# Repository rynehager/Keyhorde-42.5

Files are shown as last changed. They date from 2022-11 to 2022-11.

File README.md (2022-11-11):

# Keyhorde-42.5
Babby's first bad keyboard PCB

This is a not-quite 40%, not-quite 50% keyboard being made for the founding members of Keyhorde with the following layout:
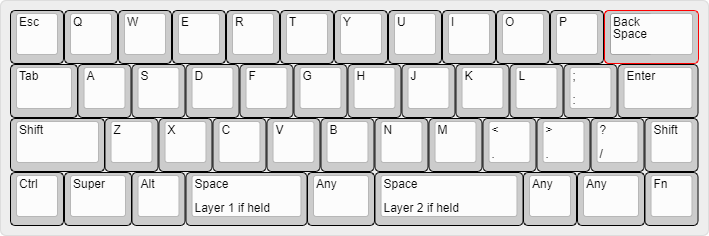
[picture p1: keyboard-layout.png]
An 11-key-wide, four-row-tall compact keyboard somwhere between a standard 40% and 50% layout


The purpose is to design a compact, USB Type-C caseless keyboard with a bare PCB aesthetic and a layout that doesn't interfere with general writing, including commonly used punctuation, but which is also as portable as possible and generally compatible with keyset options — i.e., it does not require custom or incorrect legend keys when using a set with wide compatibility. 

Schematics and layout designed in KiCAD, licensing CC0 so feel free to reuse, remix, make, sell, etc. whatever you dig bby just don't hold me responsible.

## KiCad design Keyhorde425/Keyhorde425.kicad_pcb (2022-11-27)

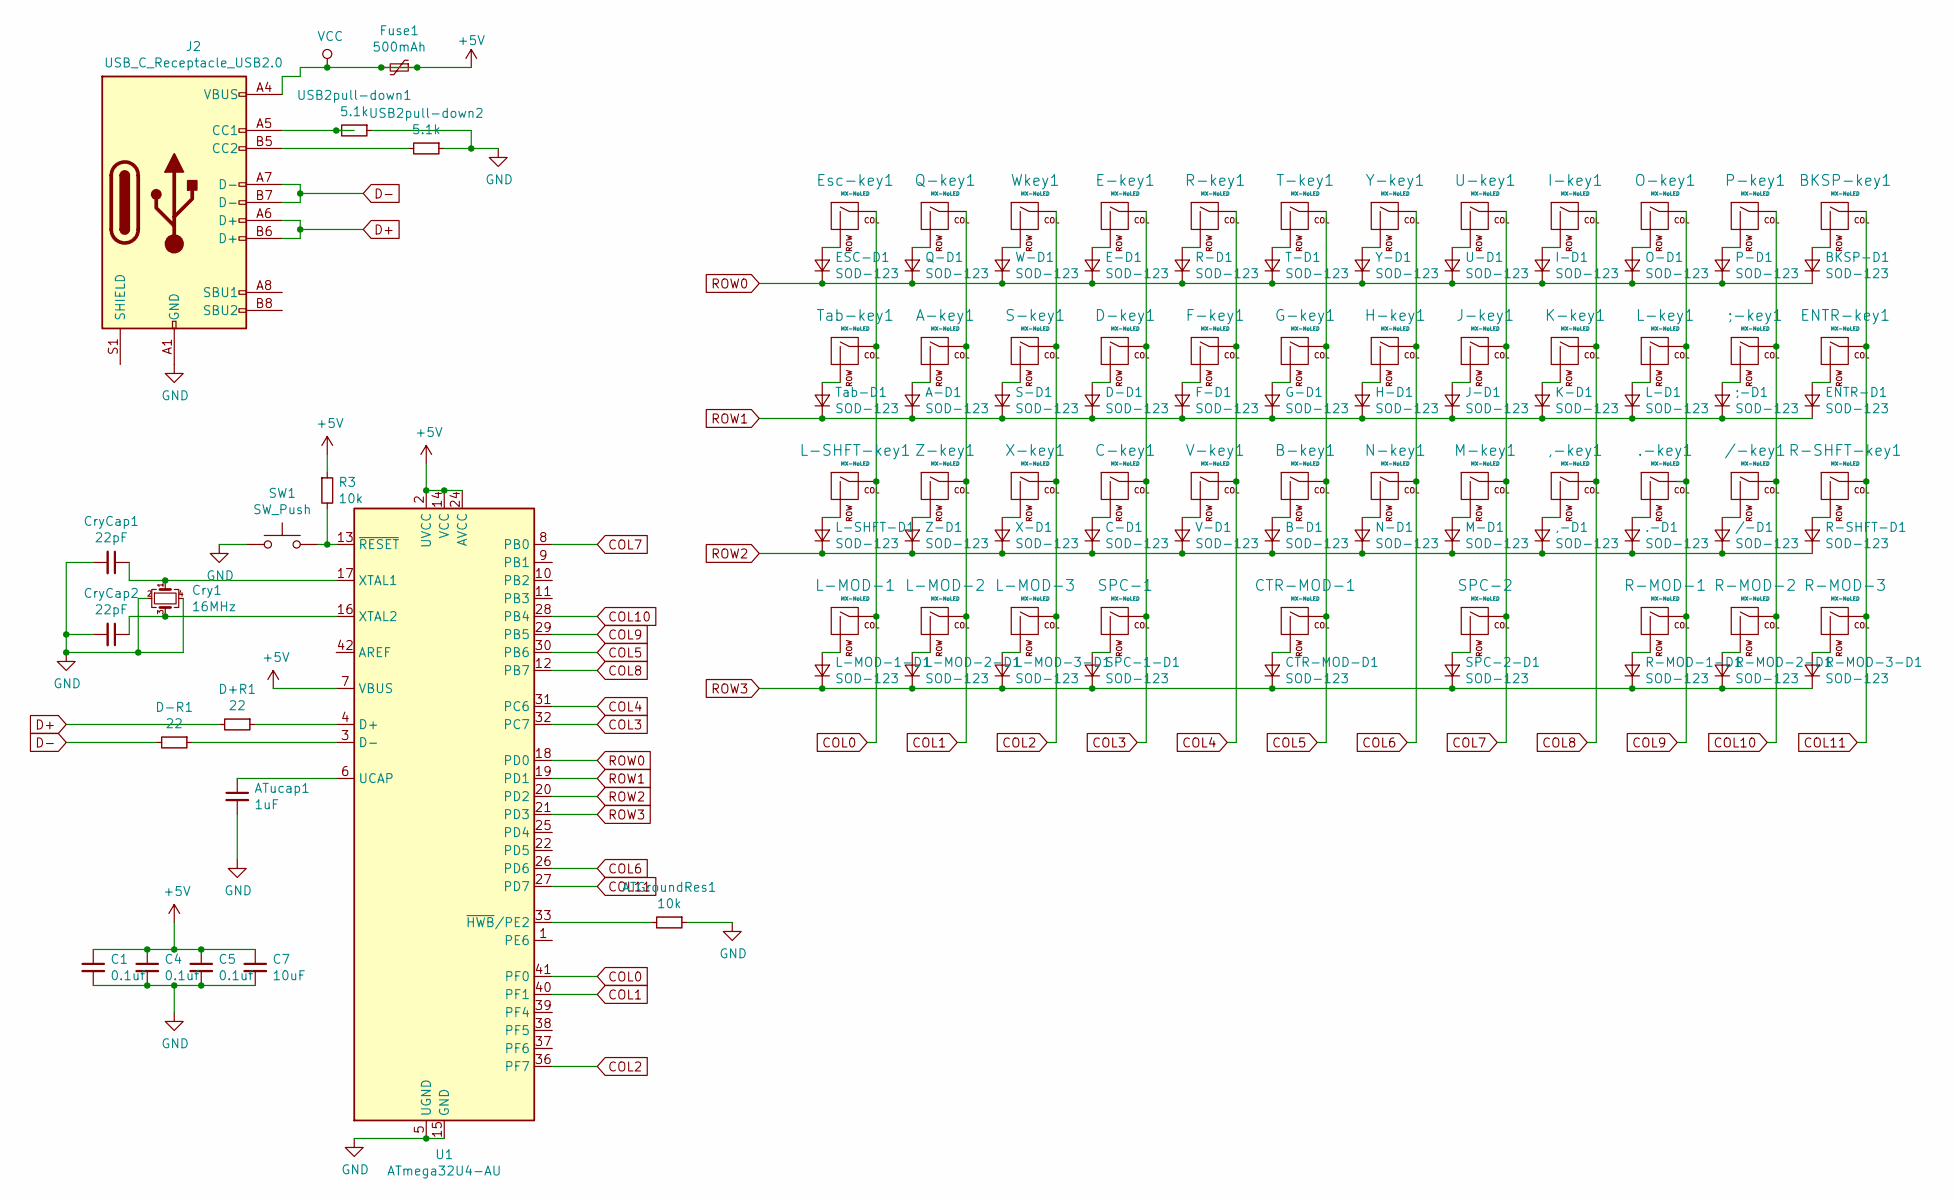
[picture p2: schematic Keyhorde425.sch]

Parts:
,-D1: SOD-123; D_SOD-123
,-key1: MX-NoLED; MX-1U-NoLED
.-D1: SOD-123; D_SOD-123
.-key1: MX-NoLED; MX-1U-NoLED
/-D1: SOD-123; D_SOD-123
/-key1: MX-NoLED; MX-1U-NoLED
;-D1: SOD-123; D_SOD-123
;-key1: MX-NoLED; MX-1U-NoLED
A-D1: SOD-123; D_SOD-123
A-key1: MX-NoLED; MX-1U-NoLED
ATGroundRes1: 10k; R_0805_2012Metric
ATucap1: 1uF; C_0805_2012Metric
B-D1: SOD-123; D_SOD-123
B-key1: MX-NoLED; MX-1U-NoLED
BKSP-D1: SOD-123; D_SOD-123
BKSP-key1: MX-NoLED; MX-1.75U-NoLED
C1, C4, C5: 0.1uf; C_0805_2012Metric
C7: 10uF; C_0805_2012Metric
C-D1: SOD-123; D_SOD-123
C-key1: MX-NoLED; MX-1U-NoLED
CTR-MOD-1: MX-NoLED; MX-1.25U-NoLED
CTR-MOD-D1: SOD-123; D_SOD-123
Cry1: 16MHz; Crystal_SMD_3225-4Pin_3.2x2.5mm
CryCap1, CryCap2: 22pF; C_0805_2012Metric
D+R1: 22; R_0805_2012Metric
D-D1: SOD-123; D_SOD-123
D-R1: 22; R_0805_2012Metric
D-key1: MX-NoLED; MX-1U-NoLED
E-D1: SOD-123; D_SOD-123
E-key1: MX-NoLED; MX-1U-NoLED
ENTR-D1: SOD-123; D_SOD-123
ENTR-key1: MX-NoLED; MX-1.5U-NoLED
ESC-D1: SOD-123; D_SOD-123
Esc-key1: MX-NoLED; MX-1U-NoLED
F-D1: SOD-123; D_SOD-123
F-key1: MX-NoLED; MX-1U-NoLED
Fuse1: 500mAh; Fuse_1206_3216Metric
G-D1: SOD-123; D_SOD-123
G-key1: MX-NoLED; MX-1U-NoLED
H-D1: SOD-123; D_SOD-123
H-key1: MX-NoLED; MX-1U-NoLED
I-D1: SOD-123; D_SOD-123
I-key1: MX-NoLED; MX-1U-NoLED
J2: USB_C_Receptacle_USB2.0; USB_C_Receptacle_Amphenol_12401610E4-2A
J-D1: SOD-123; D_SOD-123
J-key1: MX-NoLED; MX-1U-NoLED
K-D1: SOD-123; D_SOD-123
K-key1: MX-NoLED; MX-1U-NoLED
L-D1: SOD-123; D_SOD-123
L-MOD-1, L-MOD-3: MX-NoLED; MX-1U-NoLED
L-MOD-1-D1, L-MOD-2-D1, L-MOD-3-D1: SOD-123; D_SOD-123
L-MOD-2: MX-NoLED; MX-1.25U-NoLED
L-SHFT-D1: SOD-123; D_SOD-123
L-SHFT-key1: MX-NoLED; MX-1.75U-NoLED
L-key1: MX-NoLED; MX-1U-NoLED
M-D1: SOD-123; D_SOD-123
M-key1: MX-NoLED; MX-1U-NoLED
N-D1: SOD-123; D_SOD-123
N-key1: MX-NoLED; MX-1U-NoLED
O-D1: SOD-123; D_SOD-123
O-key1: MX-NoLED; MX-1U-NoLED
P-D1: SOD-123; D_SOD-123
P-key1: MX-NoLED; MX-1U-NoLED
Q-D1: SOD-123; D_SOD-123
Q-key1: MX-NoLED; MX-1U-NoLED
R3: 10k; R_0805_2012Metric
R-D1: SOD-123; D_SOD-123
R-MOD-1, R-MOD-3: MX-NoLED; MX-1U-NoLED
R-MOD-1-D1, R-MOD-2-D1, R-MOD-3-D1: SOD-123; D_SOD-123
R-MOD-2: MX-NoLED; MX-1.25U-NoLED
R-SHFT-D1: SOD-123; D_SOD-123
R-SHFT-key1: MX-NoLED; MX-1U-NoLED
R-key1: MX-NoLED; MX-1U-NoLED
S-D1: SOD-123; D_SOD-123
S-key1: MX-NoLED; MX-1U-NoLED
SPC-1: MX-NoLED; MX-2.25U-NoLED
SPC-1-D1, SPC-2-D1: SOD-123; D_SOD-123
SPC-2: MX-NoLED; MX-2.75U-NoLED
SW1: SW_Push; Reset_Pretty
T-D1: SOD-123; D_SOD-123
T-key1: MX-NoLED; MX-1U-NoLED
Tab-D1: SOD-123; D_SOD-123
Tab-key1: MX-NoLED; MX-1.25U-NoLED
U1: ATmega32U4-AU; LQFP-44_10x10mm_P0.8mm
U-D1: SOD-123; D_SOD-123
U-key1: MX-NoLED; MX-1U-NoLED
USB2pull-down1, USB2pull-down2: 5.1k; R_0805_2012Metric
V-D1: SOD-123; D_SOD-123
V-key1: MX-NoLED; MX-1U-NoLED
W-D1: SOD-123; D_SOD-123
Wkey1: MX-NoLED; MX-1U-NoLED
X-D1: SOD-123; D_SOD-123
X-key1: MX-NoLED; MX-1U-NoLED
Y-D1: SOD-123; D_SOD-123
Y-key1: MX-NoLED; MX-1U-NoLED
Z-D1: SOD-123; D_SOD-123
Z-key1: MX-NoLED; MX-1U-NoLED

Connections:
+5V: C1.1, C4.1, C5.1, C7.1, Fuse1.1, Fuse1.2, J2.A4 (VBUS), J2.A9 (VBUS), J2.B4 (VBUS), J2.B9 (VBUS), R3.1, U1.2 (UVCC), U1.7 (VBUS), U1.14 (VCC), U1.24 (AVCC), U1.34 (VCC), U1.44 (AVCC)
COL0: Esc-key1.1 (COL), L-MOD-1.1 (COL), L-SHFT-key1.1 (COL), Tab-key1.1 (COL), U1.41 (PF0)
COL1: A-key1.1 (COL), L-MOD-2.1 (COL), Q-key1.1 (COL), U1.40 (PF1), Z-key1.1 (COL)
COL2: L-MOD-3.1 (COL), S-key1.1 (COL), U1.36 (PF7), Wkey1.1 (COL), X-key1.1 (COL)
COL3: C-key1.1 (COL), D-key1.1 (COL), E-key1.1 (COL), SPC-1.1 (COL), U1.32 (PC7)
COL4: F-key1.1 (COL), R-key1.1 (COL), U1.31 (PC6), V-key1.1 (COL)
COL5: B-key1.1 (COL), CTR-MOD-1.1 (COL), G-key1.1 (COL), T-key1.1 (COL), U1.30 (PB6)
COL6: H-key1.1 (COL), N-key1.1 (COL), U1.26 (PD6), Y-key1.1 (COL)
COL7: J-key1.1 (COL), M-key1.1 (COL), SPC-2.1 (COL), U1.8 (PB0), U-key1.1 (COL)
COL8: ,-key1.1 (COL), I-key1.1 (COL), K-key1.1 (COL), U1.12 (PB7)
COL9: .-key1.1 (COL), L-key1.1 (COL), O-key1.1 (COL), R-MOD-1.1 (COL), U1.29 (PB5)
COL10: /-key1.1 (COL), ;-key1.1 (COL), P-key1.1 (COL), R-MOD-2.1 (COL), U1.28 (PB4)
COL11: BKSP-key1.1 (COL), ENTR-key1.1 (COL), R-MOD-3.1 (COL), R-SHFT-key1.1 (COL), U1.27 (PD7)
D+: D+R1.2, J2.A6 (D+), J2.B6 (D+)
D-: D-R1.2, J2.A7 (D-), J2.B7 (D-)
GND: ATGroundRes1.1, ATucap1.2, C1.2, C4.2, C5.2, C7.2, Cry1.2, Cry1.4, CryCap1.2, CryCap2.2, J2.A1 (GND), J2.A12 (GND), J2.B1 (GND), J2.B12 (GND), SW1.1, U1.5 (UGND), U1.15 (GND), U1.23 (GND), U1.35 (GND), U1.43 (GND), USB2pull-down1.1, USB2pull-down2.1
unnamed: ,-D1.2 (A), ,-key1.2 (ROW)
unnamed: .-D1.2 (A), .-key1.2 (ROW)
unnamed: /-D1.2 (A), /-key1.2 (ROW)
unnamed: ;-D1.2 (A), ;-key1.2 (ROW)
unnamed: A-D1.2 (A), A-key1.2 (ROW)
unnamed: ATGroundRes1.2, U1.33 (~HWB~/PE2)
unnamed: ATucap1.1, U1.6 (UCAP)
unnamed: B-D1.2 (A), B-key1.2 (ROW)
unnamed: BKSP-D1.2 (A), BKSP-key1.2 (ROW)
unnamed: C-D1.2 (A), C-key1.2 (ROW)
unnamed: CTR-MOD-1.2 (ROW), CTR-MOD-D1.2 (A)
unnamed: Cry1.1, CryCap1.1, U1.17 (XTAL1)
unnamed: Cry1.3, CryCap2.1, U1.16 (XTAL2)
unnamed: D+R1.1, U1.4 (D+)
unnamed: D-D1.2 (A), D-key1.2 (ROW)
unnamed: D-R1.1, U1.3 (D-)
unnamed: E-D1.2 (A), E-key1.2 (ROW)
unnamed: ENTR-D1.2 (A), ENTR-key1.2 (ROW)
unnamed: ESC-D1.2 (A), Esc-key1.2 (ROW)
unnamed: F-D1.2 (A), F-key1.2 (ROW)
unnamed: G-D1.2 (A), G-key1.2 (ROW)
unnamed: H-D1.2 (A), H-key1.2 (ROW)
unnamed: I-D1.2 (A), I-key1.2 (ROW)
unnamed: J2.A5 (CC1), USB2pull-down1.2
unnamed: J2.B5 (CC2), USB2pull-down2.2
unnamed: J-D1.2 (A), J-key1.2 (ROW)
unnamed: K-D1.2 (A), K-key1.2 (ROW)
unnamed: L-D1.2 (A), L-key1.2 (ROW)
unnamed: L-MOD-1.2 (ROW), L-MOD-1-D1.2 (A)
unnamed: L-MOD-2.2 (ROW), L-MOD-2-D1.2 (A)
unnamed: L-MOD-3.2 (ROW), L-MOD-3-D1.2 (A)
unnamed: L-SHFT-D1.2 (A), L-SHFT-key1.2 (ROW)
unnamed: M-D1.2 (A), M-key1.2 (ROW)
unnamed: N-D1.2 (A), N-key1.2 (ROW)
unnamed: O-D1.2 (A), O-key1.2 (ROW)
unnamed: P-D1.2 (A), P-key1.2 (ROW)
unnamed: Q-D1.2 (A), Q-key1.2 (ROW)
unnamed: R3.2, SW1.2, U1.13 (~RESET)
unnamed: R-D1.2 (A), R-key1.2 (ROW)
unnamed: R-MOD-1.2 (ROW), R-MOD-1-D1.2 (A)
unnamed: R-MOD-2.2 (ROW), R-MOD-2-D1.2 (A)
unnamed: R-MOD-3.2 (ROW), R-MOD-3-D1.2 (A)
unnamed: R-SHFT-D1.2 (A), R-SHFT-key1.2 (ROW)
unnamed: S-D1.2 (A), S-key1.2 (ROW)
unnamed: SPC-1.2 (ROW), SPC-1-D1.2 (A)
unnamed: SPC-2.2 (ROW), SPC-2-D1.2 (A)
unnamed: T-D1.2 (A), T-key1.2 (ROW)
unnamed: Tab-D1.2 (A), Tab-key1.2 (ROW)
unnamed: U-D1.2 (A), U-key1.2 (ROW)
unnamed: V-D1.2 (A), V-key1.2 (ROW)
unnamed: W-D1.2 (A), Wkey1.2 (ROW)
unnamed: X-D1.2 (A), X-key1.2 (ROW)
unnamed: Y-D1.2 (A), Y-key1.2 (ROW)
unnamed: Z-D1.2 (A), Z-key1.2 (ROW)
ROW0: BKSP-D1.1 (K), E-D1.1 (K), ESC-D1.1 (K), I-D1.1 (K), O-D1.1 (K), P-D1.1 (K), Q-D1.1 (K), R-D1.1 (K), T-D1.1 (K), U1.18 (PD0), U-D1.1 (K), W-D1.1 (K), Y-D1.1 (K)
ROW1: ;-D1.1 (K), A-D1.1 (K), D-D1.1 (K), ENTR-D1.1 (K), F-D1.1 (K), G-D1.1 (K), H-D1.1 (K), J-D1.1 (K), K-D1.1 (K), L-D1.1 (K), S-D1.1 (K), Tab-D1.1 (K), U1.19 (PD1)
ROW2: ,-D1.1 (K), .-D1.1 (K), /-D1.1 (K), B-D1.1 (K), C-D1.1 (K), L-SHFT-D1.1 (K), M-D1.1 (K), N-D1.1 (K), R-SHFT-D1.1 (K), U1.20 (PD2), V-D1.1 (K), X-D1.1 (K), Z-D1.1 (K)
ROW3: CTR-MOD-D1.1 (K), L-MOD-1-D1.1 (K), L-MOD-2-D1.1 (K), L-MOD-3-D1.1 (K), R-MOD-1-D1.1 (K), R-MOD-2-D1.1 (K), R-MOD-3-D1.1 (K), SPC-1-D1.1 (K), SPC-2-D1.1 (K), U1.21 (PD3)

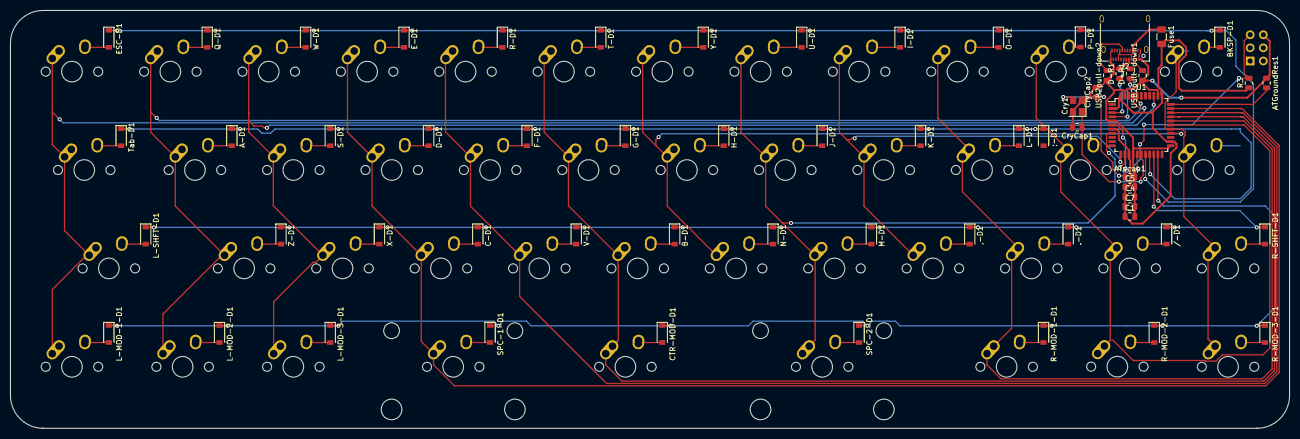
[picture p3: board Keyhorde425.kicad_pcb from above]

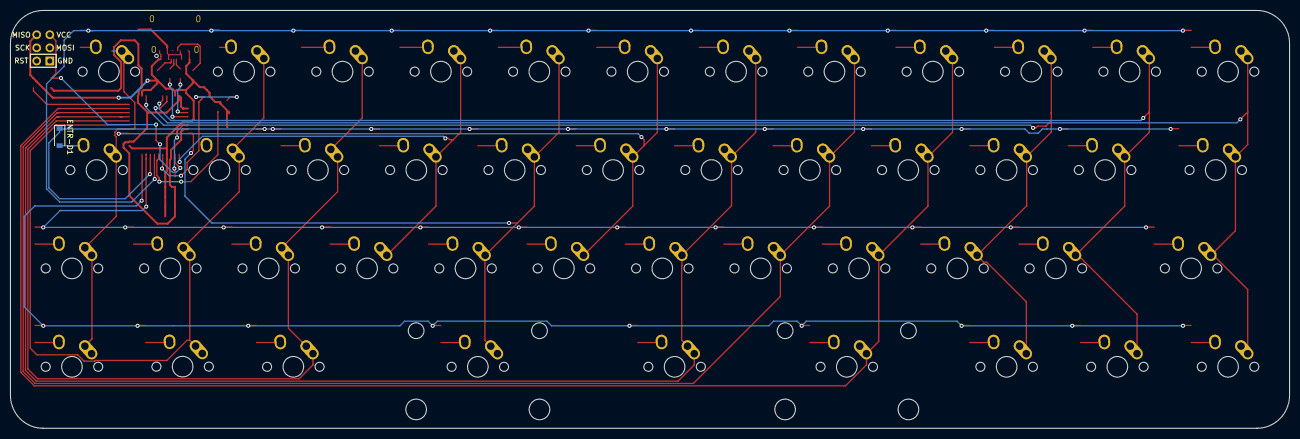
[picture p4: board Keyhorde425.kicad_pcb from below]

Board: 2 copper layers, 247.7 x 80.9 mm, 108 parts (2 on the bottom side), 74 nets.

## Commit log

2022-11-09 Initial commit with blank PCB files
    Add kicad pro and sch files.
    [Keyhorde425.kicad_pcb, Keyhorde425.sch]
2022-11-09 Add footprint libraries
    Added and linked project-specific libraries for MX switches and other parts.
2022-11-09 Schematic first draft w/USB C
    First draft of the PCB schematic before layout. Basic conversion from Mini USB 2.0 to USB Type-C, unsure if correct/complete, unsure if column wiring to controller is correct, unsure if schematic needs stabilizers included for layout.
2022-11-10 Updated schematic with bad diode footprint
    [Keyhorde425.sch]
2022-11-10 Add marbastlib submodule
    [Keyhorde425.sch]
2022-11-11 Halfway done routing traces (hopefully)
    Layout finished barring reset switch, a better Type-C port, and any issues. Begun routing.
    [Keyhorde425.sch]
2022-11-20 Take two on routing
    Wiped all routing and started over in preparation for wiping all routing and starting over again next time.
    [Keyhorde425.kicad_pcb, Keyhorde425.sch]
2022-11-27 First draft routing
    First draft of the PCB with certifiably bad routing complete. Still needs better USB Type-C footprint/receptacle
    [Keyhorde425.kicad_pcb]
